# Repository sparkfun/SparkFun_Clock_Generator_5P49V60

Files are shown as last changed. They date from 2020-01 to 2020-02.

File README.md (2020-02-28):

SparkFun Clock Generator 5P49V60
========================================

SparkFun Clock Generator 5P49V60

[*SparkFun Clock Generator 5P49V60 (BOB-15734)*](https://www.sparkfun.com/products/15734)

The SparkFun Clock Generator 5P49V60 breakout board offers a wide range of customizable frequencies in a wide range 
of different signal types using a single reference clock. Four (single output) clock outputs can generate frequencies 
from 1MHz-200MHz and eight (differential output) clock outputs can generate frequencies from 1MHz-350MHz. The frequency's 
many properties can be manipulated in code via I2C using the SparkFun Arduino Library. The SparkFun Clock Generator also 
has four banks of programmable memory for the time when it's ready to sit on its' own within the project without a microcontroller.

Repository Contents
-------------------

* **/Hardware** - Eagle design files (.brd, .sch)
* **/Production** - Production panel files (.brd)
* **/Documentation** - Datasheet for the 5P49V60

Documentation
--------------
* **[Library](https://github.com/sparkfun/SparkFun_Clock_Generator_5P49V60_Arduino_Library)** - Arduino Library for the SparkFun Clock Generator 5P49V60
* **[Hookup Guide](https://learn.sparkfun.com/tutorials/sparkfun-clock-generator-5p49v60-qwiic-hookup-guide)** - Hookup Guide for the SparkFun Clock Generator 5P49V60
* **[SparkFun Fritzing repo](https://github.com/sparkfun/Fritzing_Parts)** - Fritzing diagrams for SparkFun products.

License Information
-------------------

This product is _**open source**_! 

Please review the LICENSE.md file for license information. 

If you have any questions or concerns on licensing, please contact technical support on our [SparkFun forums](https://forum.sparkfun.com/viewforum.php?f=152).

Distributed as-is; no warranty is given.

- Your friends at SparkFun.

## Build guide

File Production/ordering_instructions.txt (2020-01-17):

panel size, 128x195mm
PCB thickness, 1.6mm
number of layers, 2
soldermask color, Red
silkscreen color, White
oz copper, 1oz
finish, HASL lead free
stencils, top+bottom
pcs per panel, 28
min trace width, 0.203200mm / 0.008000in
min drill size, 0.254000mm / 0.010000in

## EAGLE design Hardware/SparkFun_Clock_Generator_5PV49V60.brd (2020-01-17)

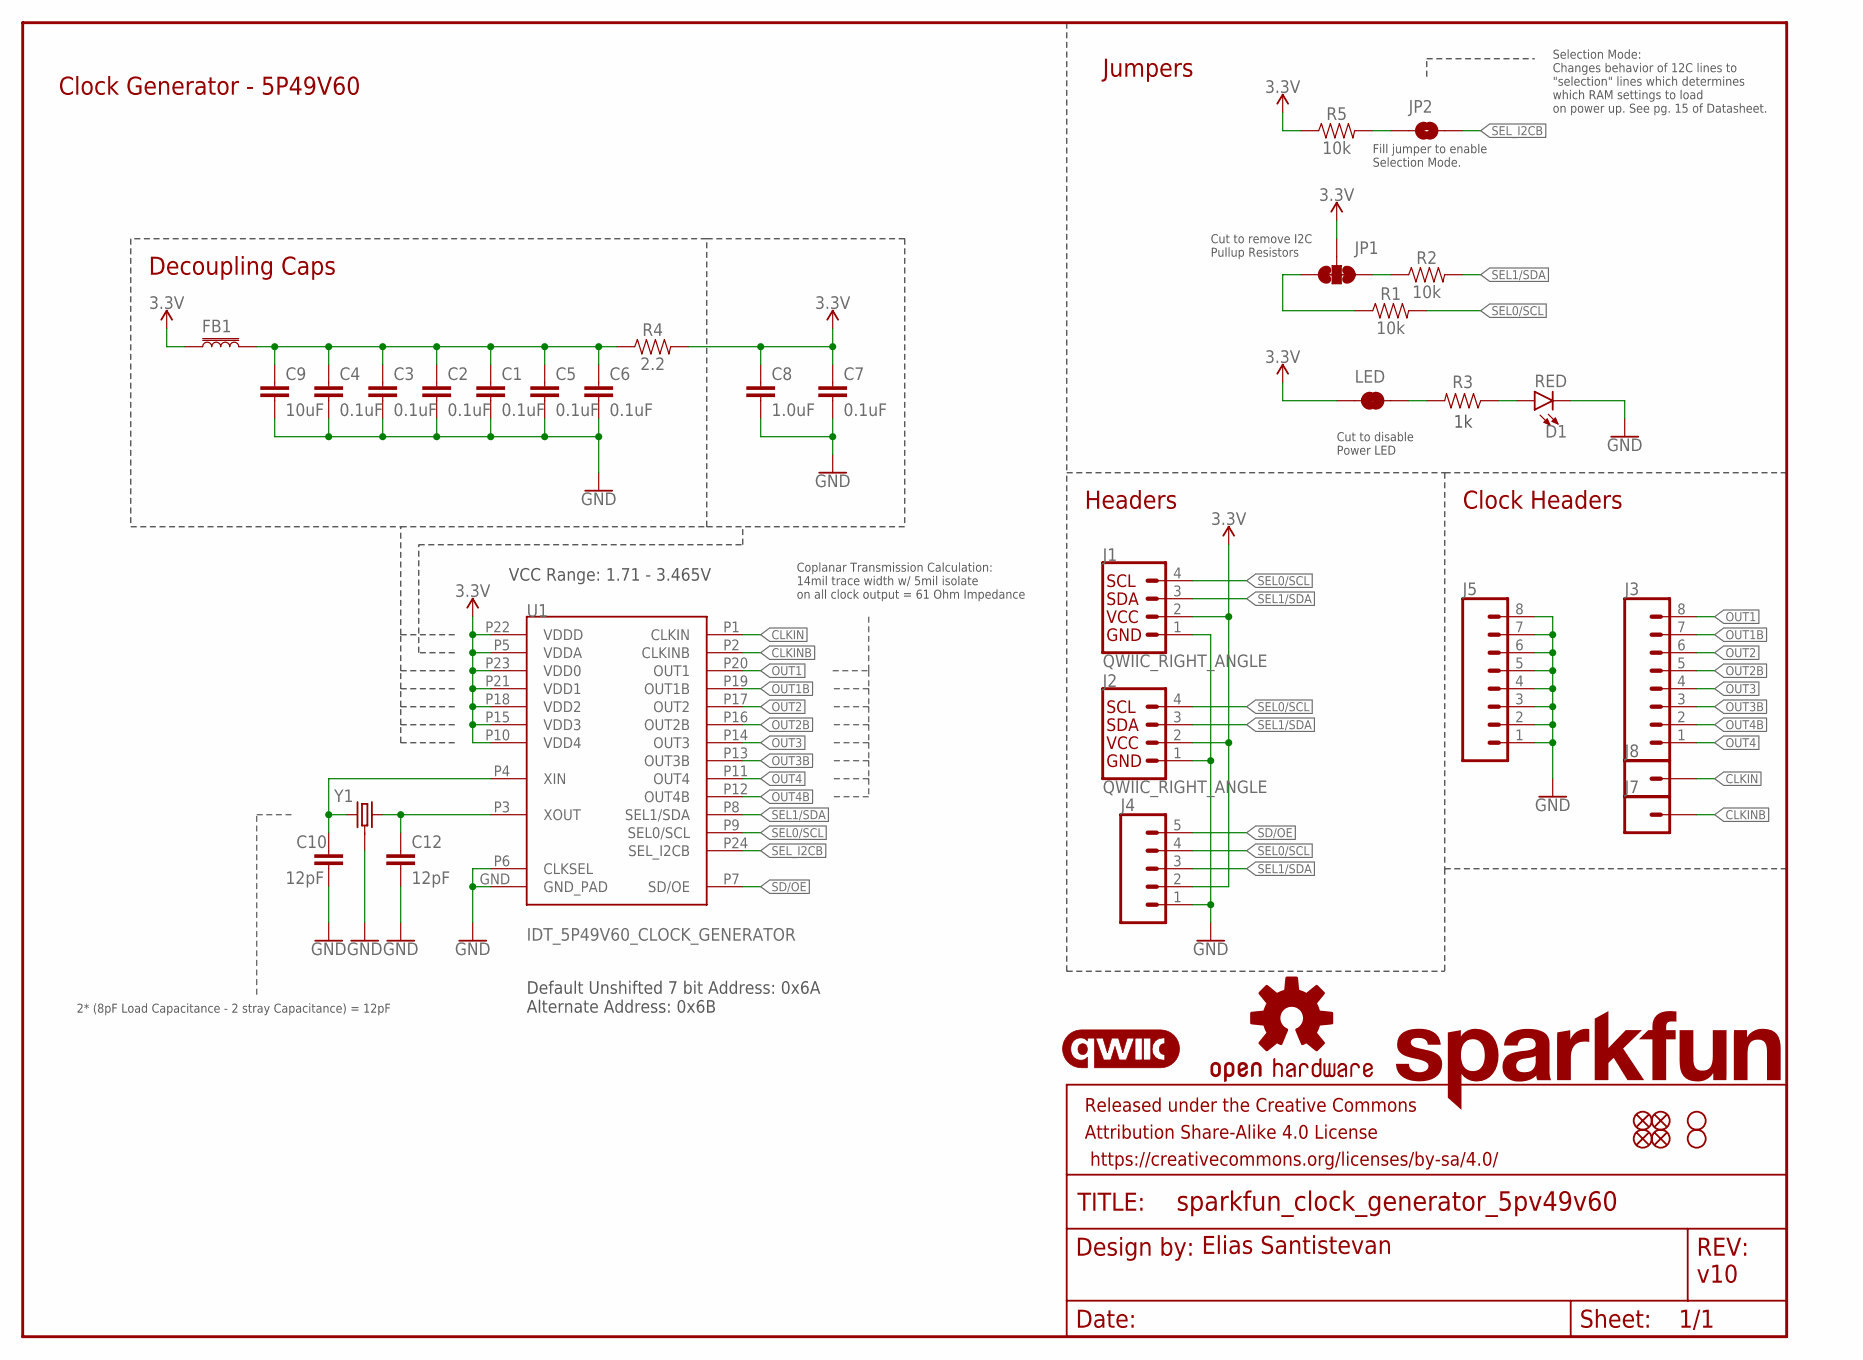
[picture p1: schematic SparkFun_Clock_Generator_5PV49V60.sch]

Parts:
C1, C2, C3, C4, C5, C6, C7: 0.1uF; 0402
C8: 1.0uF; 0402
C9: 10uF; 0603
C10, C12: 12pF; 0402
D1: RED; LED-0603
FB1: FERRITE_BEAD-120_OHM-0402; 0402
FD1, FD2, FD3, FD4: FIDUCIALUFIDUCIAL; FIDUCIAL-MICRO
FRAME1: FRAME-LETTER; CREATIVE_COMMONS
H1, H2: STAND-OFFTIGHT; STAND-OFF-TIGHT
J1, J2: QWIIC_RIGHT_ANGLE; JST04_1MM_RA
J3, J5: CONN_08NO_SILK_FEMALE_PTH; 1X08_NO_SILK
J4: CONN_05NO_SILK; 1X05_NO_SILK
J7, J8: CONN_01PTH_NO_SILK_SMALL; 1X01_SMALL
JP1: JUMPER-SMT_3_2-NC_TRACE_SILK; SMT-JUMPER_3_2-NC_TRACE_SILK
JP2: JUMPER-SMT_2_NO_SILK; SMT-JUMPER_2_NO_SILK
LED: JUMPER-SMT_2_NC_TRACE_SILK; SMT-JUMPER_2_NC_TRACE_SILK
LOGO1: SFE_LOGO_NAME.1_INCH; SFE_LOGO_NAME_.1
LOGO2: OSHW-LOGOS; OSHW-LOGO-S
LOGO3: QWIIC_LOGO_4MM; QWIIC_4MM
R1, R2, R5: 10k; 0402
R3: 1KOHM-0402-1/16W-1%; 0402
R4: 2.2; 0603
U1: IDT_5P49V60_CLOCK_GENERATOR; VFQFPN-24
Y1: 16MHz; CRYSTAL-SMD-2X2.5MM

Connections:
3.3V: C1.1, C2.1, C3.1, C4.1, C5.1, C6.1, C7.1, C8.1, C9.1, FB1.1, FB1.2, J1.2, J2.2, J4.2, JP1.2, LED.2, R4.1, R4.2, R5.1, U1.P5 (VDDA), U1.P10 (VDD4), U1.P15 (VDD3), U1.P18 (VDD2), U1.P21 (VDD1), U1.P22 (VDDD), U1.P23 (VDD0)
CLKIN: J8.P$1, U1.P1 (CLKIN)
CLKINB: J7.P$1, U1.P2 (CLKINB)
GND: C1.2, C2.2, C3.2, C4.2, C5.2, C6.2, C7.2, C8.2, C9.2, C10.2, C12.2, D1.C, J1.1, J2.1, J4.1, J5.1, J5.2, J5.3, J5.4, J5.5, J5.6, J5.7, J5.8, U1.GND (GND_PAD), U1.P6 (CLKSEL), Y1.P2 (GND), Y1.P4 (GND)
unnamed: JP1.1, R2.1
unnamed: C12.1, U1.P3 (XOUT), Y1.P1 (1)
unnamed: JP1.3, R1.1
unnamed: LED.1, R3.2
unnamed: D1.A, R3.1
unnamed: C10.1, U1.P4 (XIN), Y1.P3 (2)
unnamed: JP2.1, R5.2
OUT1: J3.8, U1.P20 (OUT1)
OUT1B: J3.7, U1.P19 (OUT1B)
OUT2: J3.6, U1.P17 (OUT2)
OUT2B: J3.5, U1.P16 (OUT2B)
OUT3: J3.4, U1.P14 (OUT3)
OUT3B: J3.3, U1.P13 (OUT3B)
OUT4: J3.1, U1.P11 (OUT4)
OUT4B: J3.2, U1.P12 (OUT4B)
SD/OE: J4.5, U1.P7 (SD/OE)
SEL0/SCL: J1.4, J2.4, J4.4, R1.2, U1.P9 (SEL0/SCL)
SEL1/SDA: J1.3, J2.3, J4.3, R2.2, U1.P8 (SEL1/SDA)
SEL_I2CB: JP2.2, U1.P24 (SEL_I2CB)

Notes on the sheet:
Elias Santistevan
v10
Clock Generator - 5P49V60
Jumpers
Headers
Clock Headers
Decoupling Caps
Cut to remove I2C Pullup Resistors
Cut to disable Power LED
VCC Range: 1.71 - 3.465V
Default Unshifted 7 bit Address: 0x6A Alternate Address: 0x6B
Fill jumper to enable Selection Mode.
Selection Mode: Changes behavior of 12C lines to "selection" lines which determines which RAM settings to load on power up. See pg. 15 of Datasheet.
Coplanar Transmission Calculation: 14mil trace width w/ 5mil isolate on all clock output = 61 Ohm Impedance
2* (8pF Load Capacitance - 2 stray Capacitance) = 12pF

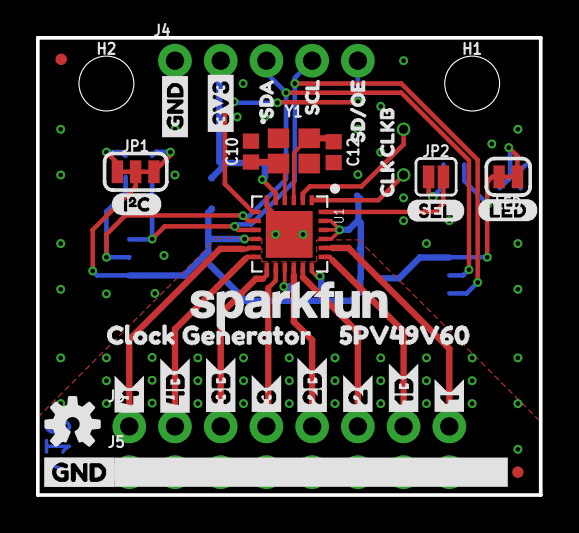
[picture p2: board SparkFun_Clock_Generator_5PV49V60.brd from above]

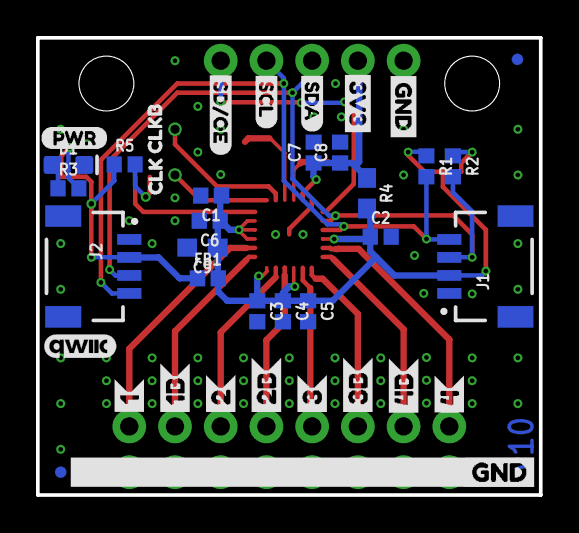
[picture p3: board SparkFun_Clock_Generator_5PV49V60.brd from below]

Board: 2 copper layers, 27.9 x 25.4 mm, 78 parts (38 on the bottom side), 23 nets.

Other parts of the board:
U$1: SEL0
U$2, U$18: 3V3-03
U$3, U$19: GND-03
U$4: PWR-()-03
U$5: SDA11
U$6: SCL10
U$7: SD#OE12
U$8, U$38: 46
U$9, U$25: 4B7
U$10, U$24: 3B5
U$11, U$37: 34
U$12, U$23: 2B3
U$13, U$27: 22
U$14, U$22: 1B1
U$15, U$26: 10
U$16: CLOCK_GENERATOR0
U$17: 5PV49V601
U$20, U$21: GND-04
U$28: SCL1
U$29: SD#OE2
U$30: SDA0
U$31, U$33: CLK12
U$32, U$34: CLKB13
U$35: I_SUPER2_C-()-03
U$36: LED0

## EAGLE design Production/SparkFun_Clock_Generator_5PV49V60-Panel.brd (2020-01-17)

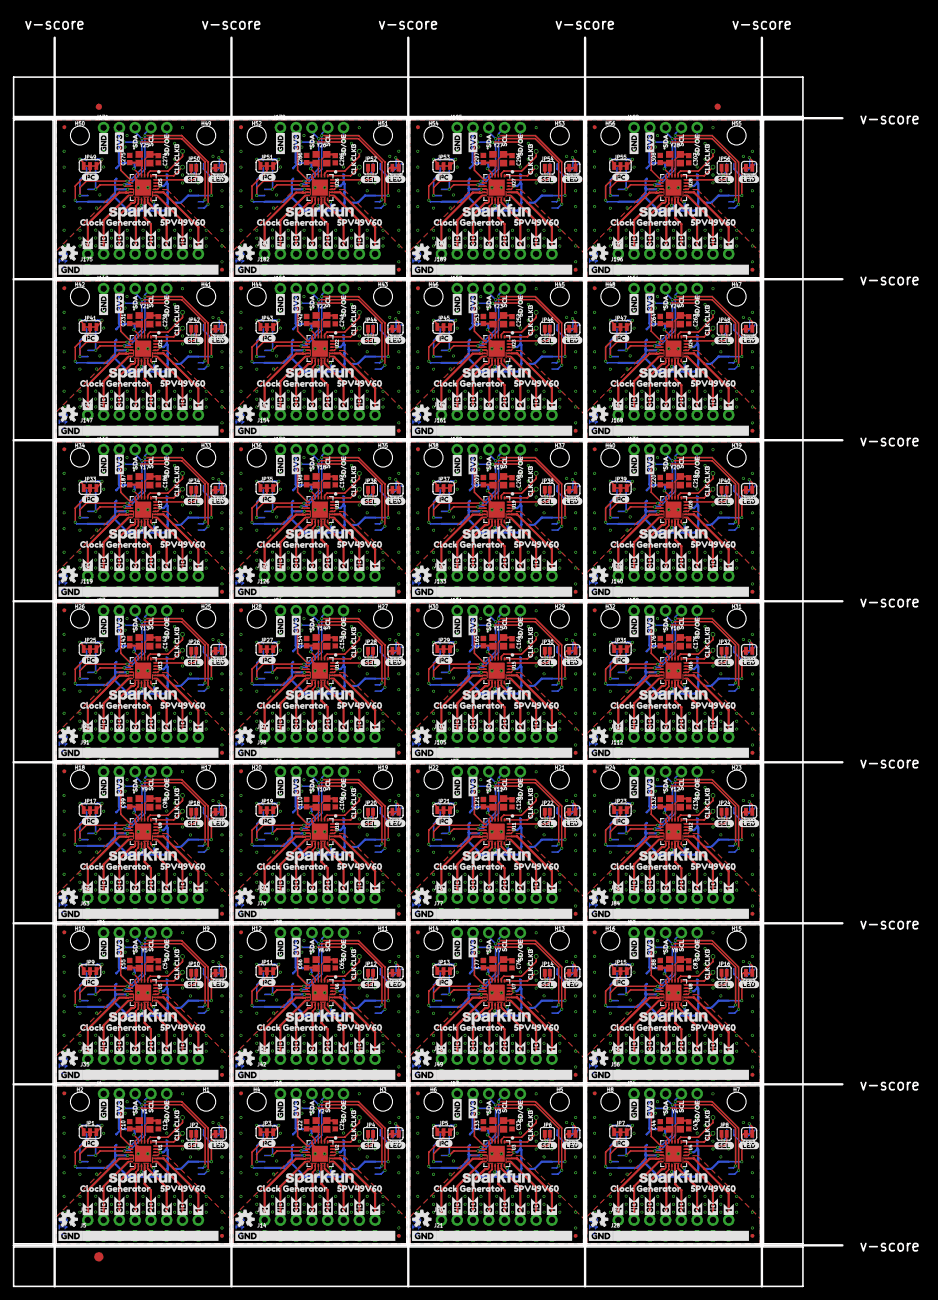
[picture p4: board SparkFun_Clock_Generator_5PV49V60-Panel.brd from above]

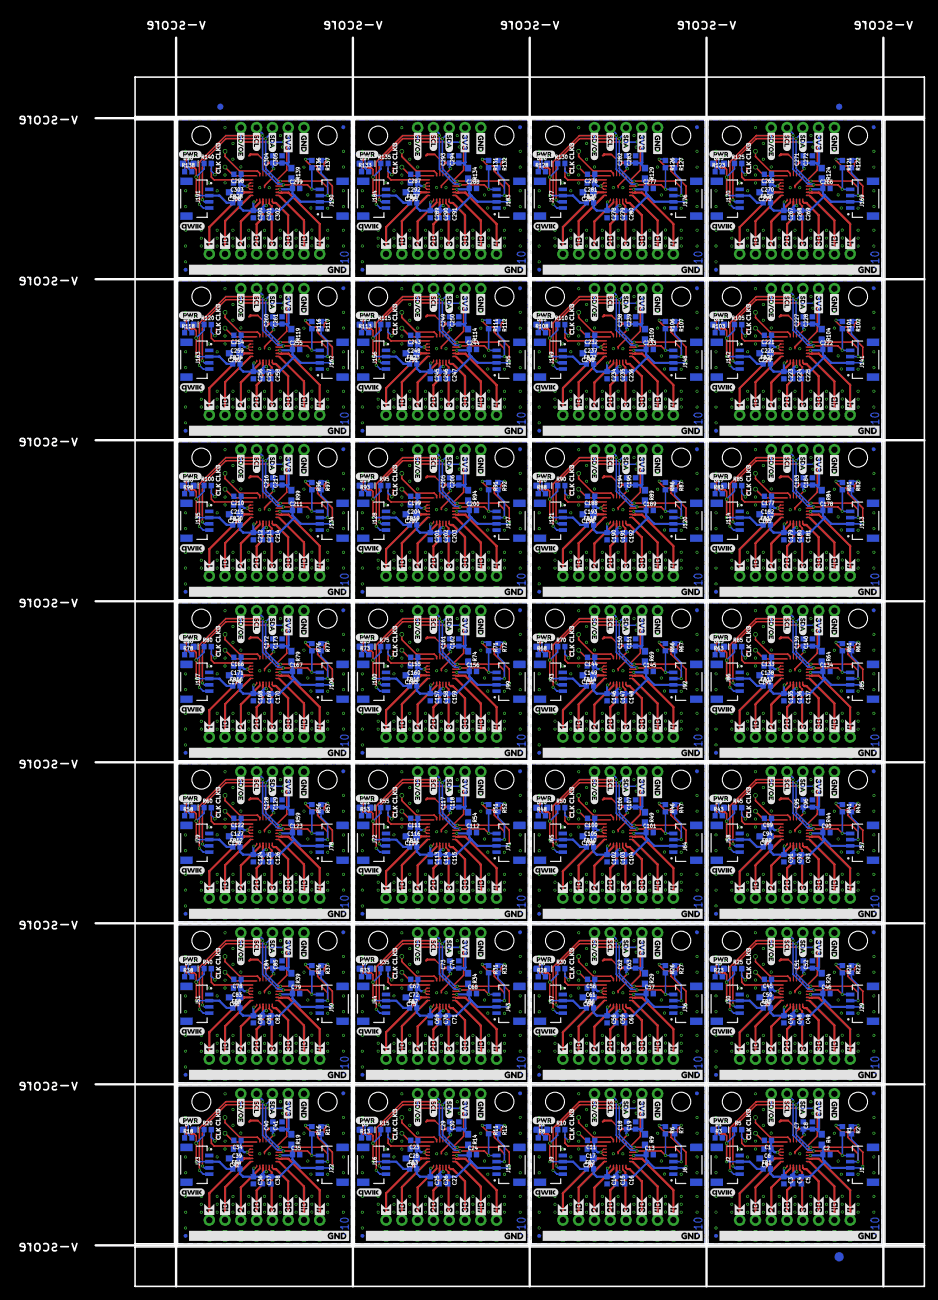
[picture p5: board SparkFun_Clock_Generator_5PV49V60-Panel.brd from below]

Board: 2 copper layers, 133.3 x 200.9 mm, 2162 parts (1067 on the bottom side), 644 nets.

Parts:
C1, C2, C3, C4, C5, C6, C7, C11, C13, C14, C15, C16, C17, C18, C23, C24, C25, C26, C27, C28, C29, C34, C35, C36, C37, C38, C39, C40, C45, C46, C47, C48, C49, C50, C51, C56, C57, C58, C59, C60, C61, C62, C67, C68, C69, C70, C71, C72, C73, C78, C79, C80, C81, C82, C83, C84, C89, C90, C91, C92, C93, C94, C95, C100, C101, C102, C103, C104, C105, C106, C111, C112, C113, C114, C115, C116, C117, C122, C123, C124, C125, C126, C127, C128, C133, C134, C135, C136, C137, C138, C139, C144, C145, C146, C147, C148, C149, C150, C155, C156, C157, C158, C159, C160, C161, C166, C167, C168, C169, C170, C171, C172, C177, C178, C179, C180, C181, C182, C183, C188, C189, C190, C191, C192, C193, C194, C199, C200, C201, C202, C203, C204, C205, C210, C211, C212, C213, C214, C215, C216, C221, C222, C223, C224, C225, C226, C227, C232, C233, C234, C235, C236, C237, C238, C243, C244, C245, C246, C247, C248, C249, C254, C255, C256, C257, C258, C259, C260, C265, C266, C267, C268, C269, C270, C271, C276, C277, C278, C279, C280, C281, C282, C287, C288, C289, C290, C291, C292, C293, C298, C299, C300, C301, C302, C303, C304: 0.1uF; 0402
C8, C19, C30, C41, C52, C63, C74, C85, C96, C107, C118, C129, C140, C151, C162, C173, C184, C195, C206, C217, C228, C239, C250, C261, C272, C283, C294, C305: 1.0uF; 0402
C9, C20, C31, C42, C53, C64, C75, C86, C97, C108, C119, C130, C141, C152, C163, C174, C185, C196, C207, C218, C229, C240, C251, C262, C273, C284, C295, C306: 10uF; 0603
C10, C12, C21, C22, C32, C33, C43, C44, C54, C55, C65, C66, C76, C77, C87, C88, C98, C99, C109, C110, C120, C121, C131, C132, C142, C143, C153, C154, C164, C165, C175, C176, C186, C187, C197, C198, C208, C209, C219, C220, C230, C231, C241, C242, C252, C253, C263, C264, C274, C275, C285, C286, C296, C297, C307, C308: 12pF; 0402
D1, D2, D3, D4, D5, D6, D7, D8, D9, D10, D11, D12, D13, D14, D15, D16, D17, D18, D19, D20, D21, D22, D23, D24, D25, D26, D27, D28: RED; LED-0603
E$1, E$2, E$3, E$4: FIDUCIAL-1X2
E$5, E$6: FIDUCIAL-1.5X3
FB1, FB2, FB3, FB4, FB5, FB6, FB7, FB8, FB9, FB10, FB11, FB12, FB13, FB14, FB15, FB16, FB17, FB18, FB19, FB20, FB21, FB22, FB23, FB24, FB25, FB26, FB27, FB28: FERRITE_BEAD-120_OHM-0402; 0402
FD1, FD2, FD3, FD4, FD5, FD6, FD7, FD8, FD9, FD10, FD11, FD12, FD13, FD14, FD15, FD16, FD17, FD18, FD19, FD20, FD21, FD22, FD23, FD24, FD25, FD26, FD27, FD28, FD29, FD30, FD31, FD32, FD33, FD34, FD35, FD36, FD37, FD38, FD39, FD40, FD41, FD42, FD43, FD44, FD45, FD46, FD47, FD48, FD49, FD50, FD51, FD52, FD53, FD54, FD55, FD56, FD57, FD58, FD59, FD60, FD61, FD62, FD63, FD64, FD65, FD66, FD67, FD68, FD69, FD70, FD71, FD72, FD73, FD74, FD75, FD76, FD77, FD78, FD79, FD80, FD81, FD82, FD83, FD84, FD85, FD86, FD87, FD88, FD89, FD90, FD91, FD92, FD93, FD94, FD95, FD96, FD97, FD98, FD99, FD100, FD101, FD102, FD103, FD104, FD105, FD106, FD107, FD108, FD109, FD110, FD111, FD112: FIDUCIALUFIDUCIAL; FIDUCIAL-MICRO
H1, H2, H3, H4, H5, H6, H7, H8, H9, H10, H11, H12, H13, H14, H15, H16, H17, H18, H19, H20, H21, H22, H23, H24, H25, H26, H27, H28, H29, H30, H31, H32, H33, H34, H35, H36, H37, H38, H39, H40, H41, H42, H43, H44, H45, H46, H47, H48, H49, H50, H51, H52, H53, H54, H55, H56: STAND-OFFTIGHT; STAND-OFF-TIGHT
J1, J2, J6, J9, J15, J16, J22, J23, J29, J30, J36, J37, J43, J44, J50, J51, J57, J58, J64, J65, J71, J72, J78, J79, J85, J86, J92, J93, J99, J100, J106, J107, J113, J114, J120, J121, J127, J128, J134, J135, J141, J142, J148, J149, J155, J156, J162, J163, J169, J170, J176, J177, J183, J184, J190, J191: QWIIC_RIGHT_ANGLE; JST04_1MM_RA
J3, J5, J13, J14, J20, J21, J27, J28, J34, J35, J41, J42, J48, J49, J55, J56, J62, J63, J69, J70, J76, J77, J83, J84, J90, J91, J97, J98, J104, J105, J111, J112, J118, J119, J125, J126, J132, J133, J139, J140, J146, J147, J153, J154, J160, J161, J167, J168, J174, J175, J181, J182, J188, J189, J195, J196: 1X08_NO_SILK
J4, J10, J17, J24, J31, J38, J45, J52, J59, J66, J73, J80, J87, J94, J101, J108, J115, J122, J129, J136, J143, J150, J157, J164, J171, J178, J185, J192: 1X05_NO_SILK
J7, J8, J11, J12, J18, J19, J25, J26, J32, J33, J39, J40, J46, J47, J53, J54, J60, J61, J67, J68, J74, J75, J81, J82, J88, J89, J95, J96, J102, J103, J109, J110, J116, J117, J123, J124, J130, J131, J137, J138, J144, J145, J151, J152, J158, J159, J165, J166, J172, J173, J179, J180, J186, J187, J193, J194: 1X01_SMALL
JP1, JP3, JP5, JP7, JP9, JP11, JP13, JP15, JP17, JP19, JP21, JP23, JP25, JP27, JP29, JP31, JP33, JP35, JP37, JP39, JP41, JP43, JP45, JP47, JP49, JP51, JP53, JP55: JUMPER-SMT_3_2-NC_TRACE_SILK; SMT-JUMPER_3_2-NC_TRACE_SILK
JP2, JP4, JP6, JP8, JP10, JP12, JP14, JP16, JP18, JP20, JP22, JP24, JP26, JP28, JP30, JP32, JP34, JP36, JP38, JP40, JP42, JP44, JP46, JP48, JP50, JP52, JP54, JP56: JUMPER-SMT_2_NO_SILK; SMT-JUMPER_2_NO_SILK
LED, LED1, LED2, LED3, LED4, LED5, LED6, LED7, LED8, LED9, LED10, LED11, LED12, LED13, LED14, LED15, LED16, LED17, LED18, LED19, LED20, LED21, LED22, LED23, LED24, LED25, LED26, LED27: JUMPER-SMT_2_NC_TRACE_SILK; SMT-JUMPER_2_NC_TRACE_SILK
LOGO1, LOGO4, LOGO7, LOGO10, LOGO13, LOGO16, LOGO19, LOGO22, LOGO25, LOGO28, LOGO31, LOGO34, LOGO37, LOGO40, LOGO43, LOGO46, LOGO49, LOGO52, LOGO55, LOGO58, LOGO61, LOGO64, LOGO67, LOGO70, LOGO73, LOGO76, LOGO79, LOGO82: SFE_LOGO_NAME.1_INCH; SFE_LOGO_NAME_.1
LOGO2, LOGO5, LOGO8, LOGO11, LOGO14, LOGO17, LOGO20, LOGO23, LOGO26, LOGO29, LOGO32, LOGO35, LOGO38, LOGO41, LOGO44, LOGO47, LOGO50, LOGO53, LOGO56, LOGO59, LOGO62, LOGO65, LOGO68, LOGO71, LOGO74, LOGO77, LOGO80, LOGO83: OSHW-LOGOS; OSHW-LOGO-S
LOGO3, LOGO6, LOGO9, LOGO12, LOGO15, LOGO18, LOGO21, LOGO24, LOGO27, LOGO30, LOGO33, LOGO36, LOGO39, LOGO42, LOGO45, LOGO48, LOGO51, LOGO54, LOGO57, LOGO60, LOGO63, LOGO66, LOGO69, LOGO72, LOGO75, LOGO78, LOGO81, LOGO84: QWIIC_LOGO_4MM; QWIIC_4MM
R1, R2, R5, R6, R7, R10, R11, R12, R15, R16, R17, R20, R21, R22, R25, R26, R27, R30, R31, R32, R35, R36, R37, R40, R41, R42, R45, R46, R47, R50, R51, R52, R55, R56, R57, R60, R61, R62, R65, R66, R67, R70, R71, R72, R75, R76, R77, R80, R81, R82, R85, R86, R87, R90, R91, R92, R95, R96, R97, R100, R101, R102, R105, R106, R107, R110, R111, R112, R115, R116, R117, R120, R121, R122, R125, R126, R127, R130, R131, R132, R135, R136, R137, R140: 10k; 0402
R3, R8, R13, R18, R23, R28, R33, R38, R43, R48, R53, R58, R63, R68, R73, R78, R83, R88, R93, R98, R103, R108, R113, R118, R123, R128, R133, R138: 1KOHM-0402-1/16W-1%; 0402
R4, R9, R14, R19, R24, R29, R34, R39, R44, R49, R54, R59, R64, R69, R74, R79, R84, R89, R94, R99, R104, R109, R114, R119, R124, R129, R134, R139: 2.2; 0603
U1, U2, U3, U4, U5, U6, U7, U8, U9, U10, U11, U12, U13, U14, U15, U16, U17, U18, U19, U20, U21, U22, U23, U24, U25, U26, U27, U28: IDT_5P49V60_CLOCK_GENERATOR; VFQFPN-24
U$1, U$76, U$114, U$152, U$190, U$228, U$266, U$304, U$342, U$380, U$418, U$456, U$494, U$532, U$570, U$608, U$646, U$684, U$722, U$760, U$798, U$836, U$874, U$912, U$950, U$988, U$1026, U$1064: SEL0
U$2, U$18, U$39, U$47, U$77, U$85, U$115, U$123, U$153, U$161, U$191, U$199, U$229, U$237, U$267, U$275, U$305, U$313, U$343, U$351, U$381, U$389, U$419, U$427, U$457, U$465, U$495, U$503, U$533, U$541, U$571, U$579, U$609, U$617, U$647, U$655, U$685, U$693, U$723, U$731, U$761, U$769, U$799, U$807, U$837, U$845, U$875, U$883, U$913, U$921, U$951, U$959, U$989, U$997, U$1027, U$1035: 3V3-03
U$3, U$19, U$40, U$48, U$78, U$86, U$116, U$124, U$154, U$162, U$192, U$200, U$230, U$238, U$268, U$276, U$306, U$314, U$344, U$352, U$382, U$390, U$420, U$428, U$458, U$466, U$496, U$504, U$534, U$542, U$572, U$580, U$610, U$618, U$648, U$656, U$686, U$694, U$724, U$732, U$762, U$770, U$800, U$808, U$838, U$846, U$876, U$884, U$914, U$922, U$952, U$960, U$990, U$998, U$1028, U$1036: GND-03
U$4, U$41, U$79, U$117, U$155, U$193, U$231, U$269, U$307, U$345, U$383, U$421, U$459, U$497, U$535, U$573, U$611, U$649, U$687, U$725, U$763, U$801, U$839, U$877, U$915, U$953, U$991, U$1029: PWR-()-03
U$5, U$42, U$80, U$118, U$156, U$194, U$232, U$270, U$308, U$346, U$384, U$422, U$460, U$498, U$536, U$574, U$612, U$650, U$688, U$726, U$764, U$802, U$840, U$878, U$916, U$954, U$992, U$1030: SDA11
U$6, U$43, U$81, U$119, U$157, U$195, U$233, U$271, U$309, U$347, U$385, U$423, U$461, U$499, U$537, U$575, U$613, U$651, U$689, U$727, U$765, U$803, U$841, U$879, U$917, U$955, U$993, U$1031: SCL10
U$7, U$44, U$82, U$120, U$158, U$196, U$234, U$272, U$310, U$348, U$386, U$424, U$462, U$500, U$538, U$576, U$614, U$652, U$690, U$728, U$766, U$804, U$842, U$880, U$918, U$956, U$994, U$1032: SD#OE12
U$8, U$38, U$65, U$68, U$103, U$106, U$141, U$144, U$179, U$182, U$217, U$220, U$255, U$258, U$293, U$296, U$331, U$334, U$369, U$372, U$407, U$410, U$445, U$448, U$483, U$486, U$521, U$524, U$559, U$562, U$597, U$600, U$635, U$638, U$673, U$676, U$711, U$714, U$749, U$752, U$787, U$790, U$825, U$828, U$863, U$866, U$901, U$904, U$939, U$942, U$977, U$980, U$1015, U$1018, U$1053, U$1056: 46
U$9, U$25, U$61, U$69, U$99, U$107, U$137, U$145, U$175, U$183, U$213, U$221, U$251, U$259, U$289, U$297, U$327, U$335, U$365, U$373, U$403, U$411, U$441, U$449, U$479, U$487, U$517, U$525, U$555, U$563, U$593, U$601, U$631, U$639, U$669, U$677, U$707, U$715, U$745, U$753, U$783, U$791, U$821, U$829, U$859, U$867, U$897, U$905, U$935, U$943, U$973, U$981, U$1011, U$1019, U$1049, U$1057: 4B7
U$10, U$24, U$60, U$70, U$98, U$108, U$136, U$146, U$174, U$184, U$212, U$222, U$250, U$260, U$288, U$298, U$326, U$336, U$364, U$374, U$402, U$412, U$440, U$450, U$478, U$488, U$516, U$526, U$554, U$564, U$592, U$602, U$630, U$640, U$668, U$678, U$706, U$716, U$744, U$754, U$782, U$792, U$820, U$830, U$858, U$868, U$896, U$906, U$934, U$944, U$972, U$982, U$1010, U$1020, U$1048, U$1058: 3B5
U$11, U$37, U$64, U$71, U$102, U$109, U$140, U$147, U$178, U$185, U$216, U$223, U$254, U$261, U$292, U$299, U$330, U$337, U$368, U$375, U$406, U$413, U$444, U$451, U$482, U$489, U$520, U$527, U$558, U$565, U$596, U$603, U$634, U$641, U$672, U$679, U$710, U$717, U$748, U$755, U$786, U$793, U$824, U$831, U$862, U$869, U$900, U$907, U$938, U$945, U$976, U$983, U$1014, U$1021, U$1052, U$1059: 34
U$12, U$23, U$59, U$72, U$97, U$110, U$135, U$148, U$173, U$186, U$211, U$224, U$249, U$262, U$287, U$300, U$325, U$338, U$363, U$376, U$401, U$414, U$439, U$452, U$477, U$490, U$515, U$528, U$553, U$566, U$591, U$604, U$629, U$642, U$667, U$680, U$705, U$718, U$743, U$756, U$781, U$794, U$819, U$832, U$857, U$870, U$895, U$908, U$933, U$946, U$971, U$984, U$1009, U$1022, U$1047, U$1060: 2B3
U$13, U$27, U$63, U$73, U$101, U$111, U$139, U$149, U$177, U$187, U$215, U$225, U$253, U$263, U$291, U$301, U$329, U$339, U$367, U$377, U$405, U$415, U$443, U$453, U$481, U$491, U$519, U$529, U$557, U$567, U$595, U$605, U$633, U$643, U$671, U$681, U$709, U$719, U$747, U$757, U$785, U$795, U$823, U$833, U$861, U$871, U$899, U$909, U$937, U$947, U$975, U$985, U$1013, U$1023, U$1051, U$1061: 22
U$14, U$22, U$58, U$74, U$96, U$112, U$134, U$150, U$172, U$188, U$210, U$226, U$248, U$264, U$286, U$302, U$324, U$340, U$362, U$378, U$400, U$416, U$438, U$454, U$476, U$492, U$514, U$530, U$552, U$568, U$590, U$606, U$628, U$644, U$666, U$682, U$704, U$720, U$742, U$758, U$780, U$796, U$818, U$834, U$856, U$872, U$894, U$910, U$932, U$948, U$970, U$986, U$1008, U$1024, U$1046, U$1062: 1B1
U$15, U$26, U$62, U$75, U$100, U$113, U$138, U$151, U$176, U$189, U$214, U$227, U$252, U$265, U$290, U$303, U$328, U$341, U$366, U$379, U$404, U$417, U$442, U$455, U$480, U$493, U$518, U$531, U$556, U$569, U$594, U$607, U$632, U$645, U$670, U$683, U$708, U$721, U$746, U$759, U$784, U$797, U$822, U$835, U$860, U$873, U$898, U$911, U$936, U$949, U$974, U$987, U$1012, U$1025, U$1050, U$1063: 10
U$16, U$45, U$83, U$121, U$159, U$197, U$235, U$273, U$311, U$349, U$387, U$425, U$463, U$501, U$539, U$577, U$615, U$653, U$691, U$729, U$767, U$805, U$843, U$881, U$919, U$957, U$995, U$1033: CLOCK_GENERATOR0
U$17, U$46, U$84, U$122, U$160, U$198, U$236, U$274, U$312, U$350, U$388, U$426, U$464, U$502, U$540, U$578, U$616, U$654, U$692, U$730, U$768, U$806, U$844, U$882, U$920, U$958, U$996, U$1034: 5PV49V601
U$20, U$21, U$56, U$57, U$94, U$95, U$132, U$133, U$170, U$171, U$208, U$209, U$246, U$247, U$284, U$285, U$322, U$323, U$360, U$361, U$398, U$399, U$436, U$437, U$474, U$475, U$512, U$513, U$550, U$551, U$588, U$589, U$626, U$627, U$664, U$665, U$702, U$703, U$740, U$741, U$778, U$779, U$816, U$817, U$854, U$855, U$892, U$893, U$930, U$931, U$968, U$969, U$1006, U$1007, U$1044, U$1045: GND-04
U$28, U$49, U$87, U$125, U$163, U$201, U$239, U$277, U$315, U$353, U$391, U$429, U$467, U$505, U$543, U$581, U$619, U$657, U$695, U$733, U$771, U$809, U$847, U$885, U$923, U$961, U$999, U$1037: SCL1
U$29, U$50, U$88, U$126, U$164, U$202, U$240, U$278, U$316, U$354, U$392, U$430, U$468, U$506, U$544, U$582, U$620, U$658, U$696, U$734, U$772, U$810, U$848, U$886, U$924, U$962, U$1000, U$1038: SD#OE2
U$30, U$51, U$89, U$127, U$165, U$203, U$241, U$279, U$317, U$355, U$393, U$431, U$469, U$507, U$545, U$583, U$621, U$659, U$697, U$735, U$773, U$811, U$849, U$887, U$925, U$963, U$1001, U$1039: SDA0
U$31, U$33, U$52, U$66, U$90, U$104, U$128, U$142, U$166, U$180, U$204, U$218, U$242, U$256, U$280, U$294, U$318, U$332, U$356, U$370, U$394, U$408, U$432, U$446, U$470, U$484, U$508, U$522, U$546, U$560, U$584, U$598, U$622, U$636, U$660, U$674, U$698, U$712, U$736, U$750, U$774, U$788, U$812, U$826, U$850, U$864, U$888, U$902, U$926, U$940, U$964, U$978, U$1002, U$1016, U$1040, U$1054: CLK12
U$32, U$34, U$53, U$67, U$91, U$105, U$129, U$143, U$167, U$181, U$205, U$219, U$243, U$257, U$281, U$295, U$319, U$333, U$357, U$371, U$395, U$409, U$433, U$447, U$471, U$485, U$509, U$523, U$547, U$561, U$585, U$599, U$623, U$637, U$661, U$675, U$699, U$713, U$737, U$751, U$775, U$789, U$813, U$827, U$851, U$865, U$889, U$903, U$927, U$941, U$965, U$979, U$1003, U$1017, U$1041, U$1055: CLKB13
U$35, U$54, U$92, U$130, U$168, U$206, U$244, U$282, U$320, U$358, U$396, U$434, U$472, U$510, U$548, U$586, U$624, U$662, U$700, U$738, U$776, U$814, U$852, U$890, U$928, U$966, U$1004, U$1042: I_SUPER2_C-()-03
U$36, U$55, U$93, U$131, U$169, U$207, U$245, U$283, U$321, U$359, U$397, U$435, U$473, U$511, U$549, U$587, U$625, U$663, U$701, U$739, U$777, U$815, U$853, U$891, U$929, U$967, U$1005, U$1043: LED0
Y1, Y2, Y3, Y4, Y5, Y6, Y7, Y8, Y9, Y10, Y11, Y12, Y13, Y14, Y15, Y16, Y17, Y18, Y19, Y20, Y21, Y22, Y23, Y24, Y25, Y26, Y27, Y28: 16MHz; CRYSTAL-SMD-2X2.5MM

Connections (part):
3.3V: C1.1, C2.1, C3.1, C4.1, C5.1, C6.1, C7.1, C8.1, C9.1, FB1.1, FB1.2, J1.2, J2.2, J4.2, JP1.2, LED.2, R4.1, R4.2, R5.1, U1.P5, U1.P10, U1.P15, U1.P18, U1.P21, U1.P22, U1.P23
3.3V1: C11.1, C13.1, C14.1, C15.1, C16.1, C17.1, C18.1, C19.1, C20.1, FB2.1, FB2.2, J6.2, J9.2, J10.2, JP3.2, LED1.2, R9.1, R9.2, R10.1, U2.P5, U2.P10, U2.P15, U2.P18, U2.P21, U2.P22, U2.P23
3.3V2: C23.1, C24.1, C25.1, C26.1, C27.1, C28.1, C29.1, C30.1, C31.1, FB3.1, FB3.2, J15.2, J16.2, J17.2, JP5.2, LED2.2, R14.1, R14.2, R15.1, U3.P5, U3.P10, U3.P15, U3.P18, U3.P21, U3.P22, U3.P23
3.3V3: C34.1, C35.1, C36.1, C37.1, C38.1, C39.1, C40.1, C41.1, C42.1, FB4.1, FB4.2, J22.2, J23.2, J24.2, JP7.2, LED3.2, R19.1, R19.2, R20.1, U4.P5, U4.P10, U4.P15, U4.P18, U4.P21, U4.P22, U4.P23
3.3V4: C45.1, C46.1, C47.1, C48.1, C49.1, C50.1, C51.1, C52.1, C53.1, FB5.1, FB5.2, J29.2, J30.2, J31.2, JP9.2, LED4.2, R24.1, R24.2, R25.1, U5.P5, U5.P10, U5.P15, U5.P18, U5.P21, U5.P22, U5.P23
3.3V5: C56.1, C57.1, C58.1, C59.1, C60.1, C61.1, C62.1, C63.1, C64.1, FB6.1, FB6.2, J36.2, J37.2, J38.2, JP11.2, LED5.2, R29.1, R29.2, R30.1, U6.P5, U6.P10, U6.P15, U6.P18, U6.P21, U6.P22, U6.P23
3.3V6: C67.1, C68.1, C69.1, C70.1, C71.1, C72.1, C73.1, C74.1, C75.1, FB7.1, FB7.2, J43.2, J44.2, J45.2, JP13.2, LED6.2, R34.1, R34.2, R35.1, U7.P5, U7.P10, U7.P15, U7.P18, U7.P21, U7.P22, U7.P23
3.3V7: C78.1, C79.1, C80.1, C81.1, C82.1, C83.1, C84.1, C85.1, C86.1, FB8.1, FB8.2, J50.2, J51.2, J52.2, JP15.2, LED7.2, R39.1, R39.2, R40.1, U8.P5, U8.P10, U8.P15, U8.P18, U8.P21, U8.P22, U8.P23
3.3V8: C89.1, C90.1, C91.1, C92.1, C93.1, C94.1, C95.1, C96.1, C97.1, FB9.1, FB9.2, J57.2, J58.2, J59.2, JP17.2, LED8.2, R44.1, R44.2, R45.1, U9.P5, U9.P10, U9.P15, U9.P18, U9.P21, U9.P22, U9.P23
3.3V9: C100.1, C101.1, C102.1, C103.1, C104.1, C105.1, C106.1, C107.1, C108.1, FB10.1, FB10.2, J64.2, J65.2, J66.2, JP19.2, LED9.2, R49.1, R49.2, R50.1, U10.P5, U10.P10, U10.P15, U10.P18, U10.P21, U10.P22, U10.P23
3.3V10: C111.1, C112.1, C113.1, C114.1, C115.1, C116.1, C117.1, C118.1, C119.1, FB11.1, FB11.2, J71.2, J72.2, J73.2, JP21.2, LED10.2, R54.1, R54.2, R55.1, U11.P5, U11.P10, U11.P15, U11.P18, U11.P21, U11.P22, U11.P23
3.3V11: C122.1, C123.1, C124.1, C125.1, C126.1, C127.1, C128.1, C129.1, C130.1, FB12.1, FB12.2, J78.2, J79.2, J80.2, JP23.2, LED11.2, R59.1, R59.2, R60.1, U12.P5, U12.P10, U12.P15, U12.P18, U12.P21, U12.P22, U12.P23
3.3V12: C133.1, C134.1, C135.1, C136.1, C137.1, C138.1, C139.1, C140.1, C141.1, FB13.1, FB13.2, J85.2, J86.2, J87.2, JP25.2, LED12.2, R64.1, R64.2, R65.1, U13.P5, U13.P10, U13.P15, U13.P18, U13.P21, U13.P22, U13.P23
3.3V13: C144.1, C145.1, C146.1, C147.1, C148.1, C149.1, C150.1, C151.1, C152.1, FB14.1, FB14.2, J92.2, J93.2, J94.2, JP27.2, LED13.2, R69.1, R69.2, R70.1, U14.P5, U14.P10, U14.P15, U14.P18, U14.P21, U14.P22, U14.P23
3.3V14: C155.1, C156.1, C157.1, C158.1, C159.1, C160.1, C161.1, C162.1, C163.1, FB15.1, FB15.2, J99.2, J100.2, J101.2, JP29.2, LED14.2, R74.1, R74.2, R75.1, U15.P5, U15.P10, U15.P15, U15.P18, U15.P21, U15.P22, U15.P23
3.3V15: C166.1, C167.1, C168.1, C169.1, C170.1, C171.1, C172.1, C173.1, C174.1, FB16.1, FB16.2, J106.2, J107.2, J108.2, JP31.2, LED15.2, R79.1, R79.2, R80.1, U16.P5, U16.P10, U16.P15, U16.P18, U16.P21, U16.P22, U16.P23
3.3V16: C177.1, C178.1, C179.1, C180.1, C181.1, C182.1, C183.1, C184.1, C185.1, FB17.1, FB17.2, J113.2, J114.2, J115.2, JP33.2, LED16.2, R84.1, R84.2, R85.1, U17.P5, U17.P10, U17.P15, U17.P18, U17.P21, U17.P22, U17.P23
3.3V17: C188.1, C189.1, C190.1, C191.1, C192.1, C193.1, C194.1, C195.1, C196.1, FB18.1, FB18.2, J120.2, J121.2, J122.2, JP35.2, LED17.2, R89.1, R89.2, R90.1, U18.P5, U18.P10, U18.P15, U18.P18, U18.P21, U18.P22, U18.P23
3.3V18: C199.1, C200.1, C201.1, C202.1, C203.1, C204.1, C205.1, C206.1, C207.1, FB19.1, FB19.2, J127.2, J128.2, J129.2, JP37.2, LED18.2, R94.1, R94.2, R95.1, U19.P5, U19.P10, U19.P15, U19.P18, U19.P21, U19.P22, U19.P23
3.3V19: C210.1, C211.1, C212.1, C213.1, C214.1, C215.1, C216.1, C217.1, C218.1, FB20.1, FB20.2, J134.2, J135.2, J136.2, JP39.2, LED19.2, R99.1, R99.2, R100.1, U20.P5, U20.P10, U20.P15, U20.P18, U20.P21, U20.P22, U20.P23
3.3V20: C221.1, C222.1, C223.1, C224.1, C225.1, C226.1, C227.1, C228.1, C229.1, FB21.1, FB21.2, J141.2, J142.2, J143.2, JP41.2, LED20.2, R104.1, R104.2, R105.1, U21.P5, U21.P10, U21.P15, U21.P18, U21.P21, U21.P22, U21.P23
3.3V21: C232.1, C233.1, C234.1, C235.1, C236.1, C237.1, C238.1, C239.1, C240.1, FB22.1, FB22.2, J148.2, J149.2, J150.2, JP43.2, LED21.2, R109.1, R109.2, R110.1, U22.P5, U22.P10, U22.P15, U22.P18, U22.P21, U22.P22, U22.P23
3.3V22: C243.1, C244.1, C245.1, C246.1, C247.1, C248.1, C249.1, C250.1, C251.1, FB23.1, FB23.2, J155.2, J156.2, J157.2, JP45.2, LED22.2, R114.1, R114.2, R115.1, U23.P5, U23.P10, U23.P15, U23.P18, U23.P21, U23.P22, U23.P23
3.3V23: C254.1, C255.1, C256.1, C257.1, C258.1, C259.1, C260.1, C261.1, C262.1, FB24.1, FB24.2, J162.2, J163.2, J164.2, JP47.2, LED23.2, R119.1, R119.2, R120.1, U24.P5, U24.P10, U24.P15, U24.P18, U24.P21, U24.P22, U24.P23
3.3V24: C265.1, C266.1, C267.1, C268.1, C269.1, C270.1, C271.1, C272.1, C273.1, FB25.1, FB25.2, J169.2, J170.2, J171.2, JP49.2, LED24.2, R124.1, R124.2, R125.1, U25.P5, U25.P10, U25.P15, U25.P18, U25.P21, U25.P22, U25.P23
3.3V25: C276.1, C277.1, C278.1, C279.1, C280.1, C281.1, C282.1, C283.1, C284.1, FB26.1, FB26.2, J176.2, J177.2, J178.2, JP51.2, LED25.2, R129.1, R129.2, R130.1, U26.P5, U26.P10, U26.P15, U26.P18, U26.P21, U26.P22, U26.P23
3.3V26: C287.1, C288.1, C289.1, C290.1, C291.1, C292.1, C293.1, C294.1, C295.1, FB27.1, FB27.2, J183.2, J184.2, J185.2, JP53.2, LED26.2, R134.1, R134.2, R135.1, U27.P5, U27.P10, U27.P15, U27.P18, U27.P21, U27.P22, U27.P23
3.3V27: C298.1, C299.1, C300.1, C301.1, C302.1, C303.1, C304.1, C305.1, C306.1, FB28.1, FB28.2, J190.2, J191.2, J192.2, JP55.2, LED27.2, R139.1, R139.2, R140.1, U28.P5, U28.P10, U28.P15, U28.P18, U28.P21, U28.P22, U28.P23
CLKIN: J8.P$1, U1.P1
CLKIN1: J12.P$1, U2.P1
CLKIN2: J19.P$1, U3.P1
CLKIN3: J26.P$1, U4.P1
CLKIN4: J33.P$1, U5.P1
CLKIN5: J40.P$1, U6.P1
CLKIN6: J47.P$1, U7.P1
CLKIN7: J54.P$1, U8.P1
CLKIN8: J61.P$1, U9.P1
CLKIN9: J68.P$1, U10.P1
CLKIN10: J75.P$1, U11.P1
CLKIN11: J82.P$1, U12.P1
CLKIN12: J89.P$1, U13.P1
CLKIN13: J96.P$1, U14.P1
CLKIN14: J103.P$1, U15.P1
CLKIN15: J110.P$1, U16.P1
CLKIN16: J117.P$1, U17.P1
CLKIN17: J124.P$1, U18.P1
CLKIN18: J131.P$1, U19.P1
CLKIN19: J138.P$1, U20.P1
CLKIN20: J145.P$1, U21.P1
CLKIN21: J152.P$1, U22.P1
CLKIN22: J159.P$1, U23.P1
CLKIN23: J166.P$1, U24.P1
CLKIN24: J173.P$1, U25.P1
CLKIN25: J180.P$1, U26.P1
CLKIN26: J187.P$1, U27.P1
CLKIN27: J194.P$1, U28.P1
CLKINB: J7.P$1, U1.P2
CLKINB1: J11.P$1, U2.P2
CLKINB2: J18.P$1, U3.P2
CLKINB3: J25.P$1, U4.P2
CLKINB4: J32.P$1, U5.P2
CLKINB5: J39.P$1, U6.P2
CLKINB6: J46.P$1, U7.P2
CLKINB7: J53.P$1, U8.P2
CLKINB8: J60.P$1, U9.P2
CLKINB9: J67.P$1, U10.P2
CLKINB10: J74.P$1, U11.P2
CLKINB11: J81.P$1, U12.P2
CLKINB12: J88.P$1, U13.P2
CLKINB13: J95.P$1, U14.P2
CLKINB14: J102.P$1, U15.P2
CLKINB15: J109.P$1, U16.P2
CLKINB16: J116.P$1, U17.P2
CLKINB17: J123.P$1, U18.P2
CLKINB18: J130.P$1, U19.P2
CLKINB19: J137.P$1, U20.P2
CLKINB20: J144.P$1, U21.P2
CLKINB21: J151.P$1, U22.P2
CLKINB22: J158.P$1, U23.P2
CLKINB23: J165.P$1, U24.P2
CLKINB24: J172.P$1, U25.P2
CLKINB25: J179.P$1, U26.P2
CLKINB26: J186.P$1, U27.P2
CLKINB27: J193.P$1, U28.P2
GND: C1.2, C2.2, C3.2, C4.2, C5.2, C6.2, C7.2, C8.2, C9.2, C10.2, C12.2, D1.C, J1.1, J2.1, J4.1, J5.1, J5.2, J5.3, J5.4, J5.5, J5.6, J5.7, J5.8, U1.GND, U1.P6, Y1.P2, Y1.P4
GND1: C11.2, C13.2, C14.2, C15.2, C16.2, C17.2, C18.2, C19.2, C20.2, C21.2, C22.2, D2.C, J6.1, J9.1, J10.1, J14.1, J14.2, J14.3, J14.4, J14.5, J14.6, J14.7, J14.8, U2.GND, U2.P6, Y2.P2, Y2.P4
GND2: C23.2, C24.2, C25.2, C26.2, C27.2, C28.2, C29.2, C30.2, C31.2, C32.2, C33.2, D3.C, J15.1, J16.1, J17.1, J21.1, J21.2, J21.3, J21.4, J21.5, J21.6, J21.7, J21.8, U3.GND, U3.P6, Y3.P2, Y3.P4
GND3: C34.2, C35.2, C36.2, C37.2, C38.2, C39.2, C40.2, C41.2, C42.2, C43.2, C44.2, D4.C, J22.1, J23.1, J24.1, J28.1, J28.2, J28.3, J28.4, J28.5, J28.6, J28.7, J28.8, U4.GND, U4.P6, Y4.P2, Y4.P4
GND4: C45.2, C46.2, C47.2, C48.2, C49.2, C50.2, C51.2, C52.2, C53.2, C54.2, C55.2, D5.C, J29.1, J30.1, J31.1, J35.1, J35.2, J35.3, J35.4, J35.5, J35.6, J35.7, J35.8, U5.GND, U5.P6, Y5.P2, Y5.P4
GND5: C56.2, C57.2, C58.2, C59.2, C60.2, C61.2, C62.2, C63.2, C64.2, C65.2, C66.2, D6.C, J36.1, J37.1, J38.1, J42.1, J42.2, J42.3, J42.4, J42.5, J42.6, J42.7, J42.8, U6.GND, U6.P6, Y6.P2, Y6.P4
GND6: C67.2, C68.2, C69.2, C70.2, C71.2, C72.2, C73.2, C74.2, C75.2, C76.2, C77.2, D7.C, J43.1, J44.1, J45.1, J49.1, J49.2, J49.3, J49.4, J49.5, J49.6, J49.7, J49.8, U7.GND, U7.P6, Y7.P2, Y7.P4
GND7: C78.2, C79.2, C80.2, C81.2, C82.2, C83.2, C84.2, C85.2, C86.2, C87.2, C88.2, D8.C, J50.1, J51.1, J52.1, J56.1, J56.2, J56.3, J56.4, J56.5, J56.6, J56.7, J56.8, U8.GND, U8.P6, Y8.P2, Y8.P4
GND8: C89.2, C90.2, C91.2, C92.2, C93.2, C94.2, C95.2, C96.2, C97.2, C98.2, C99.2, D9.C, J57.1, J58.1, J59.1, J63.1, J63.2, J63.3, J63.4, J63.5, J63.6, J63.7, J63.8, U9.GND, U9.P6, Y9.P2, Y9.P4
GND9: C100.2, C101.2, C102.2, C103.2, C104.2, C105.2, C106.2, C107.2, C108.2, C109.2, C110.2, D10.C, J64.1, J65.1, J66.1, J70.1, J70.2, J70.3, J70.4, J70.5, J70.6, J70.7, J70.8, U10.GND, U10.P6, Y10.P2, Y10.P4
GND10: C111.2, C112.2, C113.2, C114.2, C115.2, C116.2, C117.2, C118.2, C119.2, C120.2, C121.2, D11.C, J71.1, J72.1, J73.1, J77.1, J77.2, J77.3, J77.4, J77.5, J77.6, J77.7, J77.8, U11.GND, U11.P6, Y11.P2, Y11.P4
GND11: C122.2, C123.2, C124.2, C125.2, C126.2, C127.2, C128.2, C129.2, C130.2, C131.2, C132.2, D12.C, J78.1, J79.1, J80.1, J84.1, J84.2, J84.3, J84.4, J84.5, J84.6, J84.7, J84.8, U12.GND, U12.P6, Y12.P2, Y12.P4
GND12: C133.2, C134.2, C135.2, C136.2, C137.2, C138.2, C139.2, C140.2, C141.2, C142.2, C143.2, D13.C, J85.1, J86.1, J87.1, J91.1, J91.2, J91.3, J91.4, J91.5, J91.6, J91.7, J91.8, U13.GND, U13.P6, Y13.P2, Y13.P4
GND13: C144.2, C145.2, C146.2, C147.2, C148.2, C149.2, C150.2, C151.2, C152.2, C153.2, C154.2, D14.C, J92.1, J93.1, J94.1, J98.1, J98.2, J98.3, J98.4, J98.5, J98.6, J98.7, J98.8, U14.GND, U14.P6, Y14.P2, Y14.P4
GND14: C155.2, C156.2, C157.2, C158.2, C159.2, C160.2, C161.2, C162.2, C163.2, C164.2, C165.2, D15.C, J99.1, J100.1, J101.1, J105.1, J105.2, J105.3, J105.4, J105.5, J105.6, J105.7, J105.8, U15.GND, U15.P6, Y15.P2, Y15.P4
GND15: C166.2, C167.2, C168.2, C169.2, C170.2, C171.2, C172.2, C173.2, C174.2, C175.2, C176.2, D16.C, J106.1, J107.1, J108.1, J112.1, J112.2, J112.3, J112.4, J112.5, J112.6, J112.7, J112.8, U16.GND, U16.P6, Y16.P2, Y16.P4
GND16: C177.2, C178.2, C179.2, C180.2, C181.2, C182.2, C183.2, C184.2, C185.2, C186.2, C187.2, D17.C, J113.1, J114.1, J115.1, J119.1, J119.2, J119.3, J119.4, J119.5, J119.6, J119.7, J119.8, U17.GND, U17.P6, Y17.P2, Y17.P4
GND17: C188.2, C189.2, C190.2, C191.2, C192.2, C193.2, C194.2, C195.2, C196.2, C197.2, C198.2, D18.C, J120.1, J121.1, J122.1, J126.1, J126.2, J126.3, J126.4, J126.5, J126.6, J126.7, J126.8, U18.GND, U18.P6, Y18.P2, Y18.P4
GND18: C199.2, C200.2, C201.2, C202.2, C203.2, C204.2, C205.2, C206.2, C207.2, C208.2, C209.2, D19.C, J127.1, J128.1, J129.1, J133.1, J133.2, J133.3, J133.4, J133.5, J133.6, J133.7, J133.8, U19.GND, U19.P6, Y19.P2, Y19.P4
GND19: C210.2, C211.2, C212.2, C213.2, C214.2, C215.2, C216.2, C217.2, C218.2, C219.2, C220.2, D20.C, J134.1, J135.1, J136.1, J140.1, J140.2, J140.3, J140.4, J140.5, J140.6, J140.7, J140.8, U20.GND, U20.P6, Y20.P2, Y20.P4
GND20: C221.2, C222.2, C223.2, C224.2, C225.2, C226.2, C227.2, C228.2, C229.2, C230.2, C231.2, D21.C, J141.1, J142.1, J143.1, J147.1, J147.2, J147.3, J147.4, J147.5, J147.6, J147.7, J147.8, U21.GND, U21.P6, Y21.P2, Y21.P4
GND21: C232.2, C233.2, C234.2, C235.2, C236.2, C237.2, C238.2, C239.2, C240.2, C241.2, C242.2, D22.C, J148.1, J149.1, J150.1, J154.1, J154.2, J154.3, J154.4, J154.5, J154.6, J154.7, J154.8, U22.GND, U22.P6, Y22.P2, Y22.P4
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

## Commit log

2019-08-26 Initial Hardware Commit
    [SparkFun_Clock_Generator_5PV49V60.brd, SparkFun_Clock_Generator_5PV49V60.sch]
2019-09-12 Routes board
    [SparkFun_Clock_Generator_5PV49V60.brd, SparkFun_Clock_Generator_5PV49V60.sch]
2019-09-12 Adds silk, so much silk
    [SparkFun_Clock_Generator_5PV49V60.brd, SparkFun_Clock_Generator_5PV49V60.sch]
2019-09-12 Adds a few (probably) unnecessary stitching vias
    [SparkFun_Clock_Generator_5PV49V60.brd]
2019-09-13 Adds silk to jumpers and adds smaller diameter through holes for clock signals
    [SparkFun_Clock_Generator_5PV49V60.brd, SparkFun_Clock_Generator_5PV49V60.sch]
2019-09-13 Adjusts via for better ground pour
    [SparkFun_Clock_Generator_5PV49V60.brd]
2019-09-16 Minor adjustments to schematic
    [SparkFun_Clock_Generator_5PV49V60.brd, SparkFun_Clock_Generator_5PV49V60.sch]
2019-09-16 Removes pulling SEL_I2CB line from ground, and instead leaves it floating
    [SparkFun_Clock_Generator_5PV49V60.brd, SparkFun_Clock_Generator_5PV49V60.sch]
2019-09-16 Removes screw terminals in place of PTH header (with additional ground through holes)
    * Adds better silk that...just makes more sense
    * Adds ground vias to ground pad under IC
    [SparkFun_Clock_Generator_5PV49V60.brd, SparkFun_Clock_Generator_5PV49V60.sch]
2019-09-16 Moves I2C header to align with bottom header
    [SparkFun_Clock_Generator_5PV49V60.brd]
2019-09-17 Enlarges the silk on the bottom side labeling the clocks
    [SparkFun_Clock_Generator_5PV49V60.brd]
2019-09-17 Updates crystal and 12pF parts
    [SparkFun_Clock_Generator_5PV49V60.brd, SparkFun_Clock_Generator_5PV49V60.sch]
2019-09-19 Adds default address to schematic, moves design to 0,0 , updates right angle qwiic connector with value
    [SparkFun_Clock_Generator_5PV49V60.brd, SparkFun_Clock_Generator_5PV49V60.sch]
2019-09-19 Panelizes NEO-M9N and cams gerbers
    [SparkFun_Clock_Generator_5PV49V60.GBL, SparkFun_Clock_Generator_5PV49V60.GBO, SparkFun_Clock_Generator_5PV49V60.GBS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]
2019-09-19 Changes DRC to SparkFun Tight to ensure that JLCPCB could do it - parts were adjusted accordingly
    [SparkFun_Clock_Generator_5PV49V60.brd]
2019-09-19 Adds new production files for update design with different DRC
    [SparkFun_Clock_Generator_5PV49V60.brd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]
2019-09-26 Update ferrite bead
    [SparkFun_Clock_Generator_5PV49V60.brd, SparkFun_Clock_Generator_5PV49V60.sch]
2019-09-30 Updates crystal footprint, and fixes routing
    [SparkFun_Clock_Generator_5PV49V60.brd, SparkFun_Clock_Generator_5PV49V60.sch]
2019-09-30 Moves SCL silk back to its' pin
    [SparkFun_Clock_Generator_5PV49V60.brd]
2019-12-16 Radical change to design
    * Moved all parts besides crystal and IC to "bottom of board"
    * This allows for better routing of Clock signals
    * Adds 2.2Ohm series resistor to power rail
    [SparkFun_Clock_Generator_5PV49V60.brd, SparkFun_Clock_Generator_5PV49V60.sch]
2020-01-14 Updates board with select jumper to enable select mode and fixes labels
    * Also swaps clock out 4 and 4B
    [SparkFun_Clock_Generator_5PV49V60.brd, SparkFun_Clock_Generator_5PV49V60.sch]
2020-01-15 Improves ground plane pour, adds some more vias, updates packages of clock and crystal
    [SparkFun_Clock_Generator_5PV49V60.brd, SparkFun_Clock_Generator_5PV49V60.sch]
2020-01-15 Checks DRC and fixes errors
    [SparkFun_Clock_Generator_5PV49V60.brd]
2020-01-16 Fixes "SEL" text, adds second ground pour for clock lines isolate only, fixes power shorting through ferrite and resistor
    [SparkFun_Clock_Generator_5PV49V60.brd, SparkFun_Clock_Generator_5PV49V60.sch]
2020-01-16 Fixes air wires, adds clock generator to eagle library, removes buzzard label folder
    [SparkFun_Clock_Generator_5PV49V60.brd, SparkFun_Clock_Generator_5PV49V60.sch]
2020-01-17 Rotates Ferrite bead,
    [SparkFun_Clock_Generator_5PV49V60.brd]
2020-01-17 Replace "SEL" silk - not sure where it went.
    [SparkFun_Clock_Generator_5PV49V60.brd]
2020-01-17 Adds more info to schematic, removes old production files and unnecessary README's
    [SparkFun_Clock_Generator_5PV49V60.GBL, SparkFun_Clock_Generator_5PV49V60.GBO, SparkFun_Clock_Generator_5PV49V60.GBS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]
2020-01-17 Adds Production Files for a 6x7 Panel
    [SparkFun_Clock_Generator_5PV49V60-Panel.GBL, SparkFun_Clock_Generator_5PV49V60-Panel.GBO, SparkFun_Clock_Generator_5PV49V60-Panel.GBP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]
2020-01-17 Puts the aforementioned production files in the right folder.
    [SparkFun_Clock_Generator_5PV49V60-Panel.GBL, SparkFun_Clock_Generator_5PV49V60-Panel.GBO, SparkFun_Clock_Generator_5PV49V60-Panel.GBP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]
2020-01-17 Replaces previous panel due to the Panelizer changing the DRC
    [SparkFun_Clock_Generator_5PV49V60-Panel.brd, SparkFun_Clock_Generator_5PV49V60.brd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]

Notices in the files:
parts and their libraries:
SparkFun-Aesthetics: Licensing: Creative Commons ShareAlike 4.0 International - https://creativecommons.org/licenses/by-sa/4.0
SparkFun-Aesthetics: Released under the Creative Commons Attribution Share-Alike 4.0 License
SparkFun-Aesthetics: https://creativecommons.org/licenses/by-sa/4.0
